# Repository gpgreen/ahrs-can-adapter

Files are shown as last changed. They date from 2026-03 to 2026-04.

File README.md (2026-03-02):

# ahrs-can-adapter

KiCad design for a CAN adapter to a Dronecad flight board. The MCU is a
stm32f107rbt6.

## Changes

- Rev A
  Original

## Firmware

[Firmware](https://github.com/gpgreen/ahrs-can-adapter)

## Connections to Segger JTAG

I have put test points on the board, so that pogo pins can be used to program
the MCU.

[jlink web page](https://www.segger.com/products/debug-probes/j-link/technology/interface-description/)
```
**** 20 Pin connector for JTAG
                -------
    VTref      1|*   *|2 NC
    nTRST      3|*   *|4 GND
    TDI        5|*   *|6 GND
    TMS        7|*   *|8 GND
    TCK        9|*   *|10 GND
    RTCK      11|*   *|12 GND
    TDO       13|*   *|14 GND
    RESET     15|*   *|16 GND*
    DBGRQ     17|*   *|18 GND*
    5V Supply 19|*   *|20 GND*
                -------
```
From a 20pin JTAG connector, run wires to the following test pads to connect a debugger:
```
VTRef 1  <-> 3V3
SWDIO 7  <-> SWD
SWCLK 9  <-> SWC
RESET 15 <-> RST
GND   4  <-> GND
```

## Running SEGGER JLink

Run the JLink GDB server via the following:
```
JLinkGDBServer -if SWD -device STM32F103CB
```

GDB can be connected via the following:
```
gdb-multiarch --command=jlink-stm32.gdb target/thumbv7m/debug/main
```

## Running ocd
```
openocd -f interface/stlink-v3.cfg -f target/stm32f1x.cfg
```

## Credits

as always, thanks for the good work
- [Adafruit](https://www.adafruit.com)

## License

Licensed under

- MIT license ([LICENSE-MIT](LICENSE-MIT) or http://opensource.org/licenses/MIT)

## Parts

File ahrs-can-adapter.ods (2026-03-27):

Reference | Qty | Value | DNP | Exclude from BOM | Exclude from Board | Footprint | Datasheet
C1 | 1 | 4.7uF |  |  |  | Capacitor_SMD:C_0603_1608Metric | ~
C2 | 1 | 10nF |  |  |  | Capacitor_SMD:C_0603_1608Metric | ~
C3,C4,C7,C8,C9,C10,C11,C12,C16 | 9 | 1uF |  |  |  | Capacitor_SMD:C_0603_1608Metric | ~
C5,C6 | 2 | 6.8pF |  |  |  | Capacitor_SMD:C_0603_1608Metric | ~
C13 | 1 | 0.33uf |  |  |  | Capacitor_Tantalum_SMD:CP_EIA-3216-18_Kemet-A_HandSolder | ~
C14 | 1 | 10uf |  |  |  | Capacitor_Tantalum_SMD:CP_EIA-3216-18_Kemet-A_HandSolder | ~
C15 | 1 | 0.1uf |  |  |  | Capacitor_SMD:C_0603_1608Metric | ~
D1 | 1 | LED |  |  |  | LED_SMD:LED_0805_2012Metric | ~
D2 | 1 | LED1 |  |  |  | LED_SMD:LED_0805_2012Metric | ~
D3 | 1 | LED2 |  |  |  | LED_SMD:LED_0805_2012Metric | ~
D4 | 1 | LED3 |  |  |  | LED_SMD:LED_0805_2012Metric | ~
F1 | 1 | Polyfuse |  |  |  | Fuse:Fuse_Bourns_MF-SM_7.98x5.44mm | ~
H1,H2,H3,H4 | 4 | MountingHole |  |  |  | MountingHole:MountingHole_2.5mm_Pad | ~
J1 | 1 | Flight Power |  |  |  | Connector_JST:JST_GH_BM06B-GHS-TBT_1x06-1MP_P1.25mm_Vertical | ~
J2 | 1 | Flight Telem |  |  |  | Connector_JST:JST_GH_BM04B-GHS-TBT_1x04-1MP_P1.25mm_Vertical | ~
J3 | 1 | CAN IN |  |  |  | Connector_Dsub:DSUB-9_Socket_Horizontal_P2.77x2.84mm_EdgePinOffset14.56mm_Housed_MountingHolesOffset8.20mm | ~
J4 | 1 | CAN OUT |  |  |  | Connector_Dsub:DSUB-9_Socket_Horizontal_P2.77x2.84mm_EdgePinOffset14.56mm_Housed_MountingHolesOffset8.20mm | ~
R1 | 1 | 10K |  |  |  | Resistor_SMD:R_0603_1608Metric | ~
R2,R4,R5 | 3 | 1K |  |  |  | Resistor_SMD:R_0603_1608Metric | ~
R3 | 1 | 1.5K |  |  |  | Resistor_SMD:R_0603_1608Metric | ~
SW1 | 1 | Reset |  |  |  | custom_footprint:OnShine KPT-1187B | ~
TP1 | 1 | 3V3 |  |  |  | TestPoint:TestPoint_Pad_D2.0mm | ~
TP2 | 1 | GND |  |  |  | TestPoint:TestPoint_Pad_D2.0mm | ~
TP3 | 1 | SWD |  |  |  | TestPoint:TestPoint_Pad_D2.0mm | ~
TP4 | 1 | SWC |  |  |  | TestPoint:TestPoint_Pad_D2.0mm | ~
TP5 | 1 | RST |  |  |  | TestPoint:TestPoint_Pad_D2.0mm | ~
U1 | 1 | MPM3610-adafruit 5V |  |  |  | custom_footprint:Adafruit_MPM3610
U2 | 1 | UA78M33CDCYR |  |  |  | Package_TO_SOT_SMD:SOT-223-3_TabPin2 | http://www.ti.com/lit/ds/symlink/ua78.pdf
U3,U6 | 2 | LTC2875-S8 |  |  |  | Package_SO:SOIC-8_3.9x4.9mm_P1.27mm | https://www.analog.com/media/en/technical-documentation/data-sheets/2875f.pdf
U4 | 1 | STM32G474RET6 |  |  |  | Package_QFP:LQFP-64_10x10mm_P0.5mm | https://www.st.com/resource/en/datasheet/stm32g474re.pdf
U5,U7 | 2 | VCAN26A2 |  |  |  | Package_TO_SOT_SMD:SOT-323_SC-70 | https://www.vishay.com/docs/85894/vcan26a2-03g.pdf
Y1 | 1 | 24MHz |  |  |  | Crystal:Crystal_SMD_2016-4Pin_2.0x1.6mm | ~

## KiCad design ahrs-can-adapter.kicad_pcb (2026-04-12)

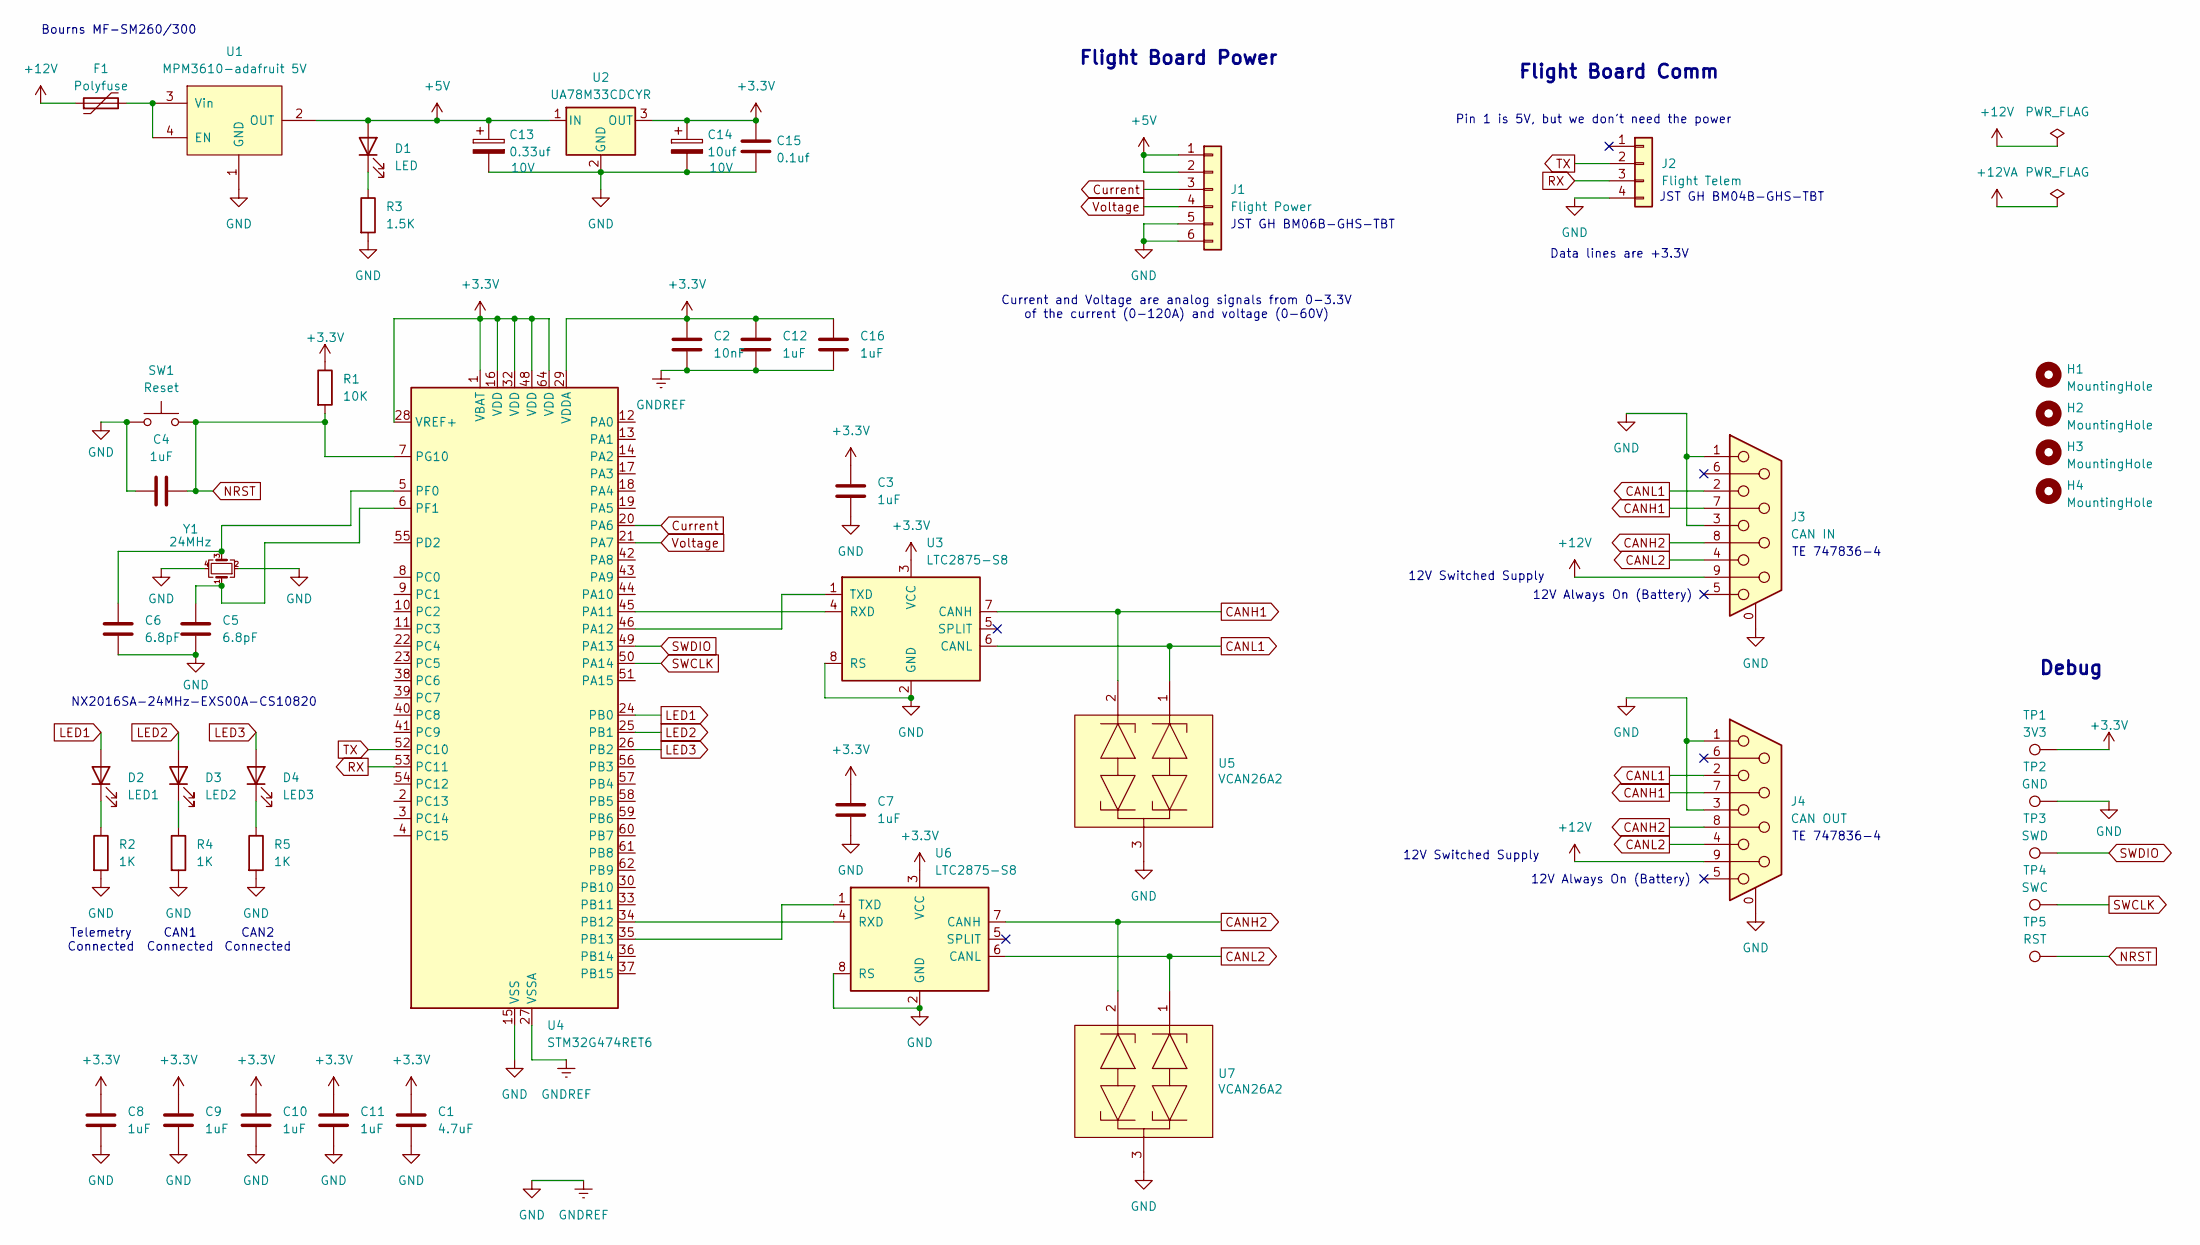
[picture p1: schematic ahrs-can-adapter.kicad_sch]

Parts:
C1: 4.7uF; C_0603_1608Metric
C2: 10nF; C_0603_1608Metric
C3, C4, C7, C8, C9, C10, C11, C12, C16: 1uF; C_0603_1608Metric
C5, C6: 6.8pF; C_0603_1608Metric
C13: 0.33uf; CP_EIA-3216-18_Kemet-A_HandSolder; Voltage 10V
C14: 10uf; CP_EIA-3216-18_Kemet-A_HandSolder; Voltage 10V
C15: 0.1uf; C_0603_1608Metric
D1: LED; LED_0805_2012Metric
D2: LED1; LED_0805_2012Metric
D3: LED2; LED_0805_2012Metric
D4: LED3; LED_0805_2012Metric
F1: Polyfuse; Fuse_Bourns_MF-SM_7.98x5.44mm
H1, H2, H3, H4: MountingHole; MountingHole_2.5mm_Pad
J1: Flight Power; JST_GH_BM06B-GHS-TBT_1x06-1MP_P1.25mm_Vertical
J2: Flight Telem; JST_GH_BM04B-GHS-TBT_1x04-1MP_P1.25mm_Vertical
J3: CAN IN; DSUB-9_Socket_Horizontal_P2.77x2.84mm_EdgePinOffset14.56mm_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
J4: CAN OUT; DSUB-9_Socket_Horizontal_P2.77x2.84mm_EdgePinOffset14.56mm_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
R1: 10K; R_0603_1608Metric
R2, R4, R5: 1K; R_0603_1608Metric
R3: 1.5K; R_0603_1608Metric
SW1: Reset; OnShine KPT-1187B
TP1: 3V3; TestPoint_Pad_D2.0mm
TP2: GND; TestPoint_Pad_D2.0mm
TP3: SWD; TestPoint_Pad_D2.0mm
TP4: SWC; TestPoint_Pad_D2.0mm
TP5: RST; TestPoint_Pad_D2.0mm
U1: MPM3610-adafruit 5V; Adafruit_MPM3610
U2: UA78M33CDCYR; SOT-223-3_TabPin2
U3, U6: LTC2875-S8; SOIC-8_3.9x4.9mm_P1.27mm
U4: STM32G474RET6; LQFP-64_10x10mm_P0.5mm
U5, U7: VCAN26A2; SOT-323_SC-70
Y1: 24MHz; Crystal_SMD_2016-4Pin_2.0x1.6mm

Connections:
+3.3V: C1.1, C2.1, C3.1, C7.1, C8.1, C9.1, C10.1, C11.1, C12.1, C14.1, C15.1, C16.1, R1.1, TP1.1 (1_1), U2.3 (OUT), U3.3 (VCC), U4.1 (VBAT), U4.16 (VDD), U4.28 (VREF+), U4.29 (VDDA), U4.32 (VDD), U4.48 (VDD), U4.64 (VDD), U6.3 (VCC)
+5V: C13.1, D1.2 (A), J1.1, J1.2, U1.2 (OUT), U2.1 (IN)
+12V: F1.1, J3.9 (9_9), J4.9 (9_9)
CANH1: J3.7 (7_7), J4.7 (7_7), U3.7 (CANH), U5.2
CANH2: J3.8 (8_8), J4.8 (8_8), U6.7 (CANH), U7.2
CANL1: J3.2 (2_2), J4.2 (2_2), U3.6 (CANL), U5.1
CANL2: J3.4 (4_4), J4.4 (4_4), U6.6 (CANL), U7.1
Current: J1.3, U4.20 (PA6)
GND: C1.2, C2.2, C3.2, C4.2, C5.2, C6.2, C7.2, C8.2, C9.2, C10.2, C11.2, C12.2, C13.2, C14.2, C15.2, C16.2, J1.5, J1.6, J2.4, J3.0 (PAD), J3.1 (1_1), J3.3 (3_3), J3.SH (PAD_0), J4.0 (PAD), J4.1 (1_1), J4.3 (3_3), J4.SH (PAD_0), R2.2, R3.2, R4.2, R5.2, SW1.1, TP2.1 (1_1), U1.1 (GND), U2.2 (GND), U3.2 (GND), U3.8 (RS), U4.15 (VSS), U4.27 (VSSA), U4.31 (VSS), U4.47 (VSS), U4.63 (VSS), U5.3, U6.2 (GND), U6.8 (RS), U7.3, Y1.2, Y1.4
LED1: D2.2 (A), U4.24 (PB0)
LED2: D3.2 (A), U4.25 (PB1)
LED3: D4.2 (A), U4.26 (PB2)
NRST: C4.1, R1.2, SW1.2, TP5.1 (1_1), U4.7 (PG10)
unnamed: D1.1 (K), R3.1
unnamed: D2.1 (K), R2.1
unnamed: D3.1 (K), R4.1
unnamed: D4.1 (K), R5.1
unnamed: F1.2, U1.3 (Vin), U1.4 (EN)
unnamed: U3.4 (RXD), U4.45 (PA11)
unnamed: U3.1 (TXD), U4.46 (PA12)
unnamed: U4.34 (PB12), U6.4 (RXD)
unnamed: U4.35 (PB13), U6.1 (TXD)
unnamed: C6.1, U4.5 (PF0), Y1.3
unnamed: C5.1, U4.6 (PF1), Y1.1
RX: J2.3, U4.53 (PC11)
SWCLK: TP4.1 (1_1), U4.50 (PA14)
SWDIO: TP3.1 (1_1), U4.49 (PA13)
TX: J2.2, U4.52 (PC10)
Voltage: J1.4, U4.21 (PA7)

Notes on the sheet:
Telemetry Connected
TE 747836-4
CAN2 Connected
CAN1 Connected
Debug
JST GH BM04B-GHS-TBT
12V Switched Supply
12V Always On (Battery)
Pin 1 is 5V, but we don't need the power
JST GH BM06B-GHS-TBT
Flight Board Power
NX2016SA-24MHz-EXS00A-CS10820
Current and Voltage are analog signals from 0-3.3V of the current (0-120A) and voltage (0-60V)
Flight Board Comm
Bourns MF-SM260/300
Data lines are +3.3V

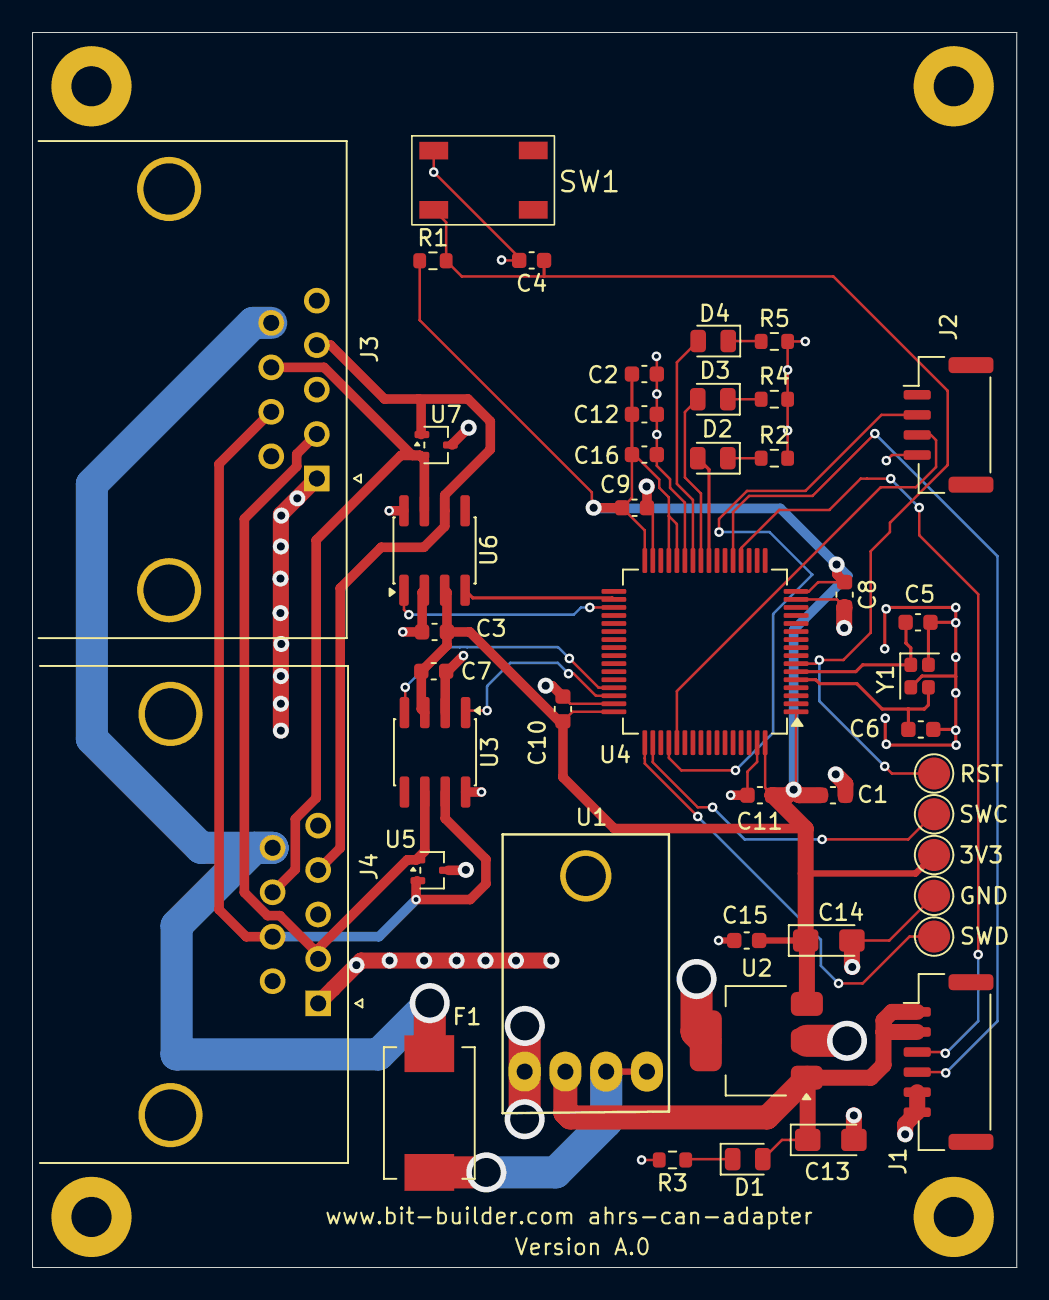
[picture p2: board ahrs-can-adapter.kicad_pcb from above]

Board: 2 copper layers, 61.3 x 77.0 mm, 48 parts (0 on the bottom side), 29 nets.

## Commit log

2026-03-04 Fixed crystal circuit
    [ahrs-can-adapter.kicad_pcb, ahrs-can-adapter.kicad_sch, ahrs-can-adapter.ods]
2026-03-17 Changed flight board connectors
    [ahrs-can-adapter.kicad_pcb, ahrs-can-adapter.kicad_sch]
2026-03-24 Changed MCU to stm32g474ret6
    [ahrs-can-adapter.kicad_pcb, ahrs-can-adapter.kicad_sch]
2026-03-26 updated crystal circuit
    [ahrs-can-adapter.kicad_pcb, ahrs-can-adapter.kicad_sch]
2026-03-27 update crystal footprint
    [ahrs-can-adapter.kicad_pcb, ahrs-can-adapter.ods]
2026-04-12 Changed telemetry uart pins
    [ahrs-can-adapter.kicad_pcb, ahrs-can-adapter.kicad_sch]
